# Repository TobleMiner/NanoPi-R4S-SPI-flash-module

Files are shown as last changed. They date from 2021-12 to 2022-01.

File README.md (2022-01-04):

NanoPi R4S NOR flash adapter
============================

This PCB provides the NanoPi R4S with NOR flash as a secondary or primary
boot option.  
Compared to most micro SD cards NOR flash is inherently much more reliable
due to its internal structure. While this comes with its own set of
drawbacks notably small storage size and low write speed it is very well
suited for many appliance applications.  
The dual LAN port configuration of the NanoPi R4S makes it a perfect match
for router operations. This NOR flash adapter module could for example be
paired with OpenWRT to provide a highly reliable router platform.

In addition to the SPI flash this board also features an STM32G031G6U6
microcontroller. It is connected to an I2C bus on the NanoPi R4S.  
The MCU has control over the reset and write protect lines of the SPI NOR
flash chip. Thus it can be used to disable the flash chip if booting from
alternate sources is desired. The write-protect line can be used to
implement custom tamper-proof storage designs.

To notify users of operations performed by the MCU a small dynamic
speaker is provided.

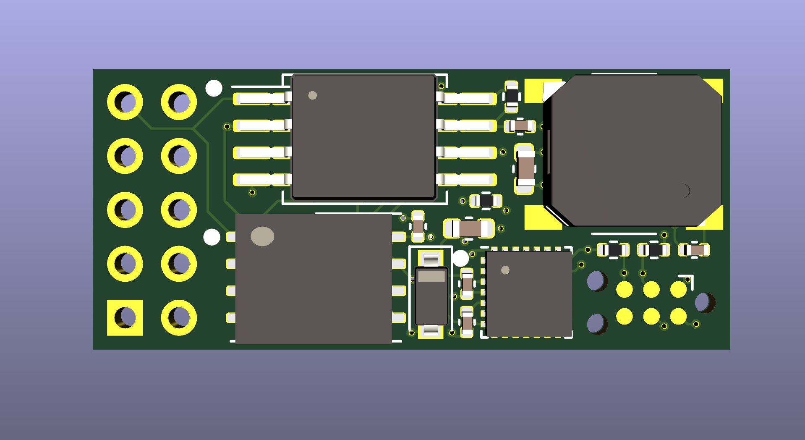
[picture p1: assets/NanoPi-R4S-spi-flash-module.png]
PCB front


# Ordering

**WARNING: Do not order rev1.0 at JLC. The partnumber for the MCU is incorrect!**

The fabrication files inside `fab` are JLCPCB-ready. I'd suggest ordering
with a 1mm board thickness. This will ensure the easiest fit in small
cases.

The board can be fully assmebled by JLC. The required fabrication files
can also be found in the `fab` directory.  
If you do not plan on using the MCU on the board you can simply unselect
the following components on JLC's website during ordering:

- U5
- D1
- LS1
- C4
- C5
- C6

This will make the boards significantly cheaper, especially when ordering
small quantities.

# Installation

Due to space constraints imposed by many cases the recommended
installation method for this board is to solder it directly to the
expansion header of the NanoPi R4S. Make sure to push the board down onto
the expansion header as far as possible before soldering it into place.

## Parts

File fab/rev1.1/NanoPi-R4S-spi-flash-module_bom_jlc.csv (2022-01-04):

Comment | Designator | Footprint | LCSC Part #
1uF | C1,C3 | C_0402_1005Metric | C52923
100nF | C2,C7 | C_0402_1005Metric | C1525
47uF | C4,C5 | C_0603_1608Metric | C140782
10uF | C6 | C_0402_1005Metric | C15525
1N4148W | D1 | D_SOD-123 | C81598
Speaker | LS1 | MLT_7525 | C95299
10k | R1,R2,R3,R4 | R_0402_1005Metric | C25744
W25Q32JVSS | U1 | SOIC-8_5.23x5.23mm_P1.27mm | C190799
STM32G031GxU | U5 | Package_QFN_ST_ST_UFQFPN-28_4x4mm_P0.5mm | C432211

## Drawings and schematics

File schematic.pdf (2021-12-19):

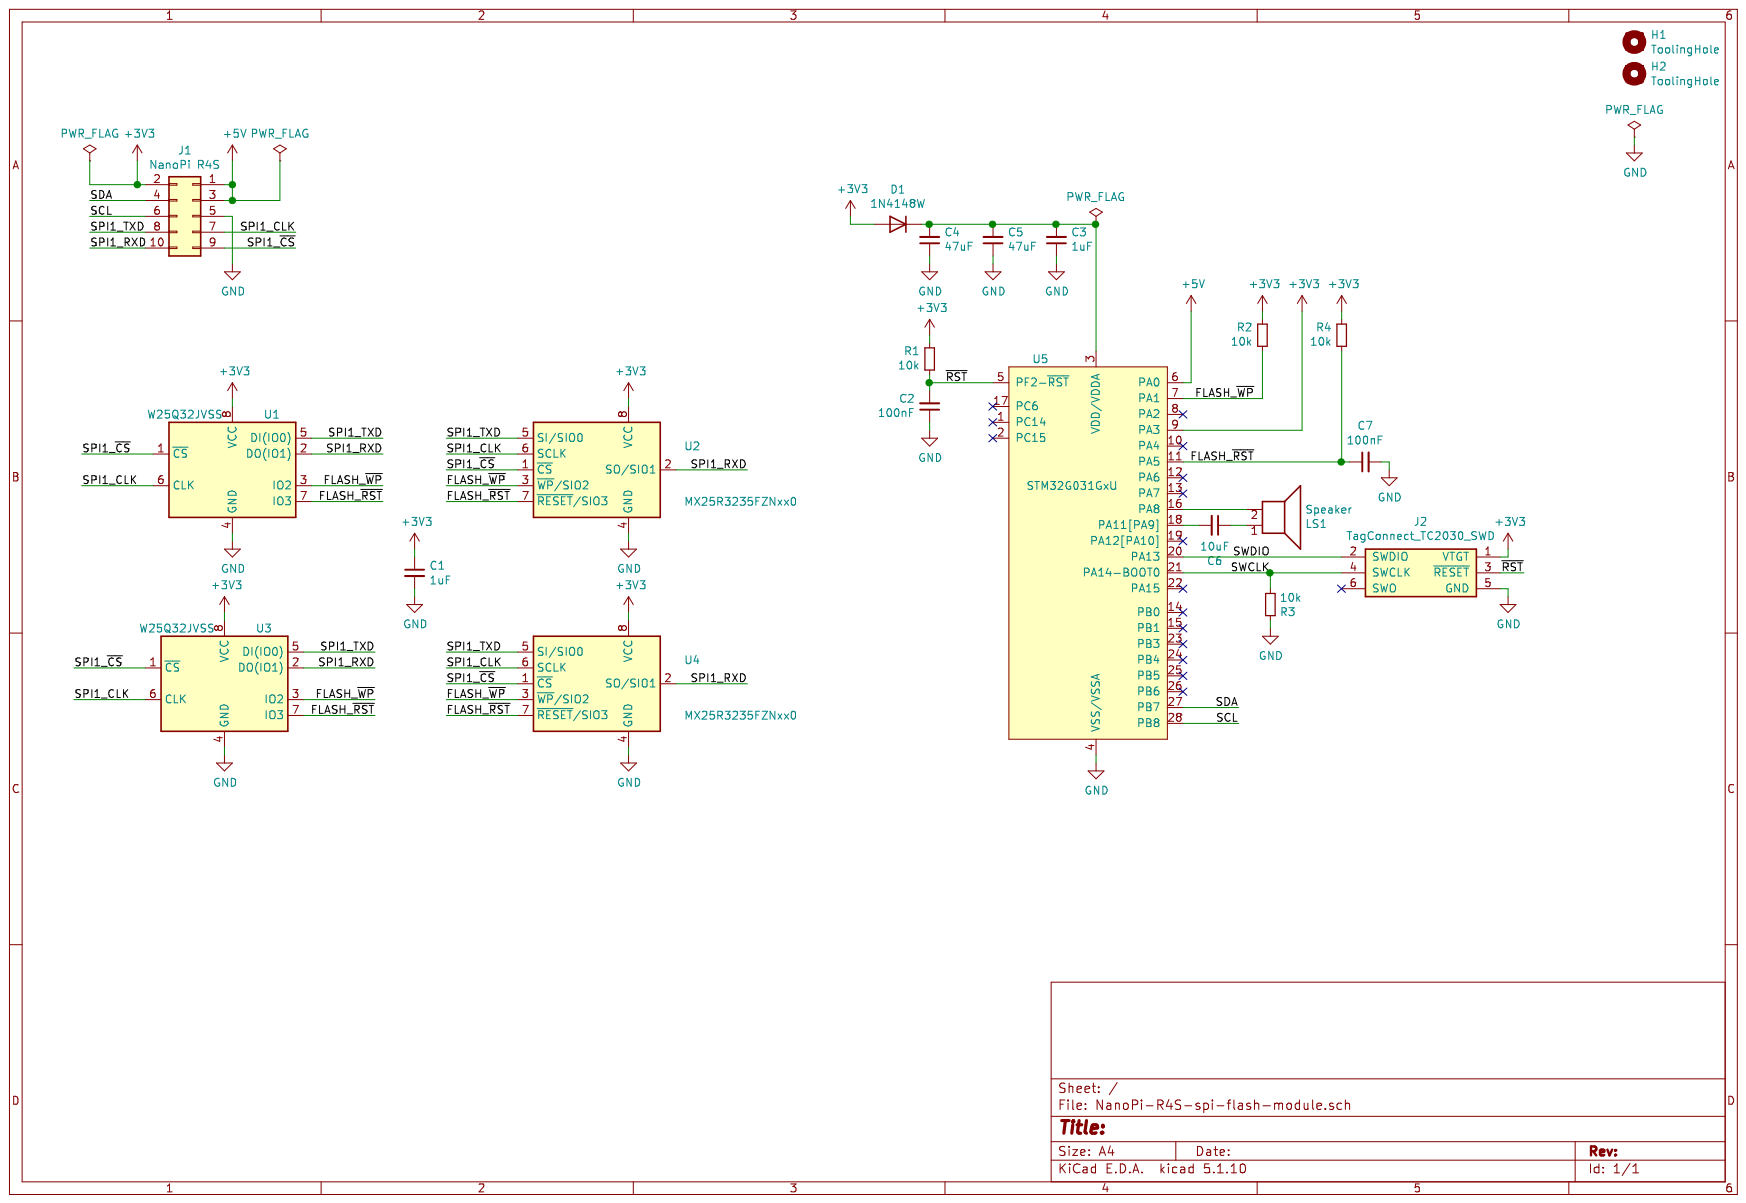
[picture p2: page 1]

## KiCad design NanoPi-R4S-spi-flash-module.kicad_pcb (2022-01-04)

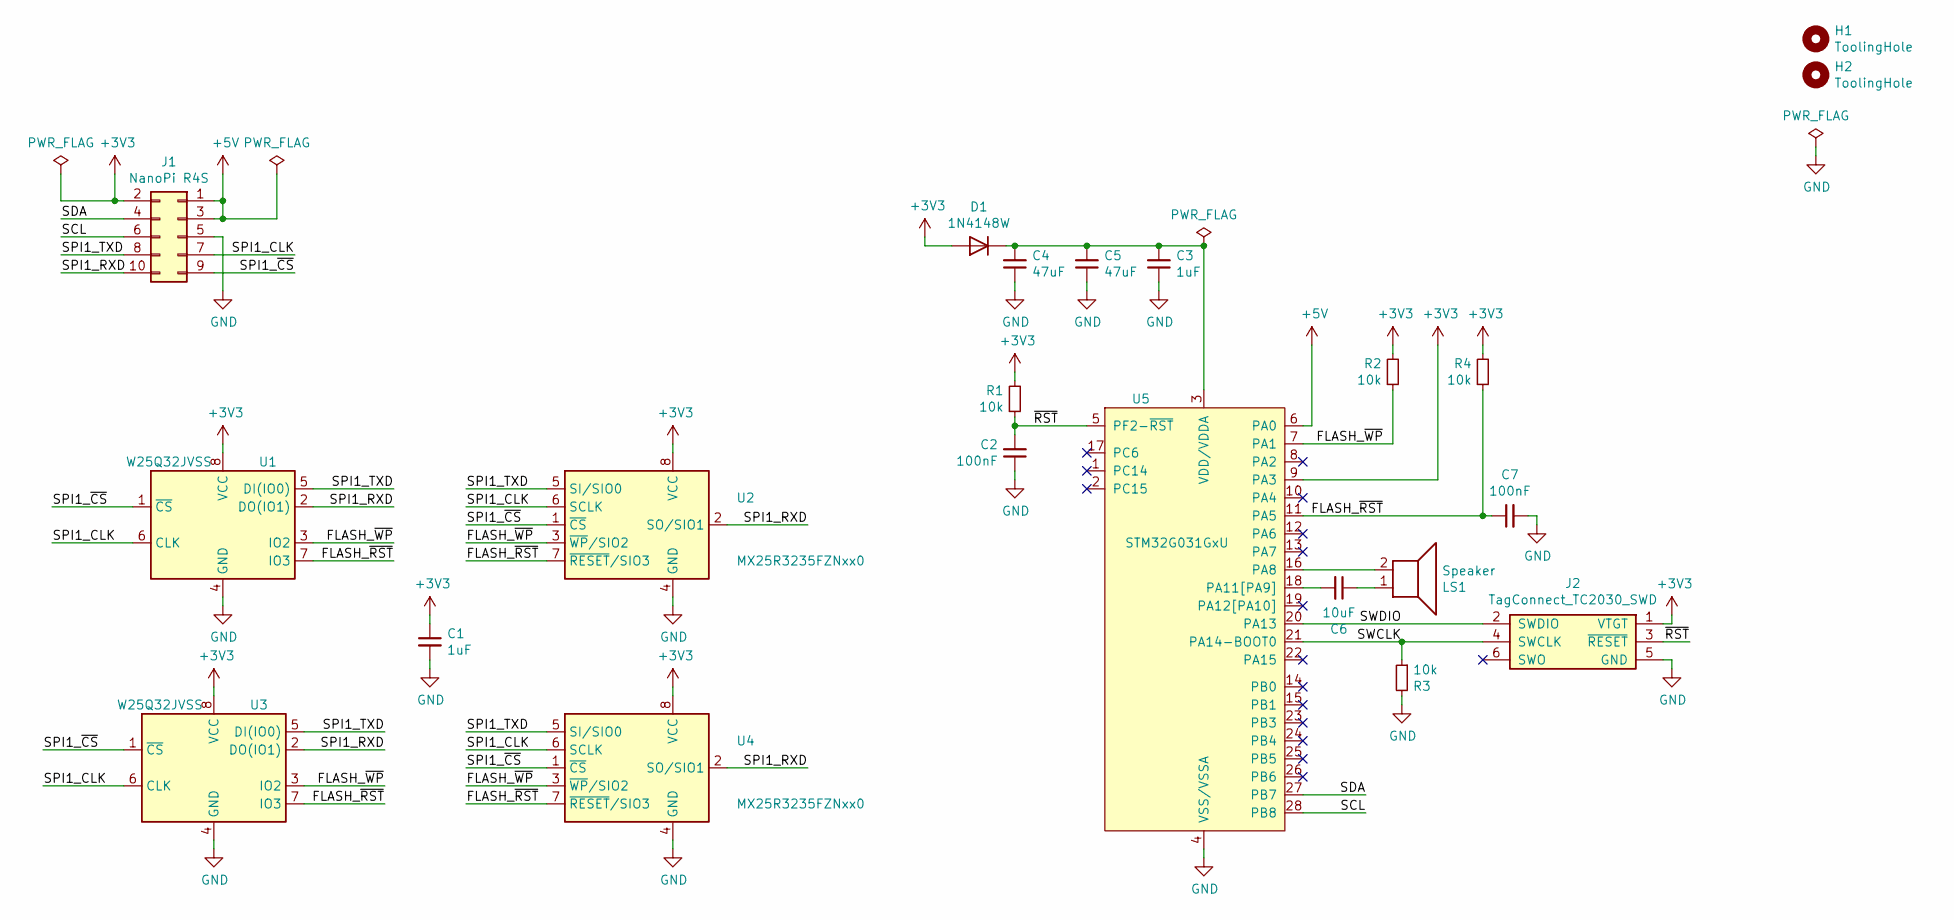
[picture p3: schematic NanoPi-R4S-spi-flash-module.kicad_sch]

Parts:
C1, C3: 1uF; C_0402_1005Metric; LCSC C52923
C2, C7: 100nF; C_0402_1005Metric; LCSC C1525
C4, C5: 47uF; C_0603_1608Metric; LCSC C140782
C6: 10uF; C_0402_1005Metric; LCSC C15525
D1: 1N4148W; D_SOD-123; LCSC C81598
H1, H2: ToolingHole; ToolingHole_JLCSMT
J1: NanoPi R4S; PinHeader_2x05_P2.54mm_Vertical
J2: TagConnect_TC2030_SWD; Tag-Connect_TC2030-IDC-NL_2x03_P1.27mm_Vertical
LS1: Speaker; MLT_7525; LCSC C95299
R1, R2, R3, R4: 10k; R_0402_1005Metric; LCSC C25744
U1: W25Q32JVSS; SOIC-8_5.23x5.23mm_P1.27mm; LCSC C190799
U2: MX25R3235FZNxx0; WSON-8-1EP_6x5mm_P1.27mm_EP3.4x4mm
U3: W25Q32JVSS; SOIC-8_7.5x5.85mm_P1.27mm
U4: MX25R3235FZNxx0; WSON-8-1EP_8x6mm_P1.27mm_EP3.4x4.3mm
U5: STM32G031GxU; Package_QFN_ST_ST_UFQFPN-28_4x4mm_P0.5mm; LCSC C432211

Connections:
+3V3: C1.1, D1.2 (A), J1.2, J2.1 (VTGT), R1.2, R2.2, R4.2, U1.8 (VCC), U2.8 (VCC), U3.8 (VCC), U4.8 (VCC), U5.9 (PA3)
+5V: J1.1, J1.3, U5.6 (PA0)
/FLASH_~RST: C7.1, R4.1, U1.7 (IO3), U2.7 (~RESET/SIO3), U3.7 (IO3), U4.7 (~RESET/SIO3), U5.11 (PA5)
/FLASH_~WP: R2.1, U1.3 (IO2), U2.3 (~WP/SIO2), U3.3 (IO2), U4.3 (~WP/SIO2), U5.7 (PA1)
/SCL: J1.6, U5.28 (PB8)
/SDA: J1.4, U5.27 (PB7)
/SPI1_CLK: J1.7, U1.6 (CLK), U2.6 (SCLK), U3.6 (CLK), U4.6 (SCLK)
/SPI1_RXD: J1.10, U1.2 (DO(IO1)), U2.2 (SO/SIO1), U3.2 (DO(IO1)), U4.2 (SO/SIO1)
/SPI1_TXD: J1.8, U1.5 (DI(IO0)), U2.5 (SI/SIO0), U3.5 (DI(IO0)), U4.5 (SI/SIO0)
/SPI1_~CS: J1.9, U1.1 (~CS), U2.1 (~CS), U3.1 (~CS), U4.1 (~CS)
/SWCLK: J2.4 (SWCLK), R3.1, U5.21 (PA14-BOOT0)
/SWDIO: J2.2 (SWDIO), U5.20 (PA13)
/~RST: C2.2, J2.3 (~RESET), R1.1, U5.5 (PF2-~RST)
GND: C1.2, C2.1, C3.1, C4.1, C5.1, C7.2, J1.5, J2.5 (GND), R3.2, U1.4 (GND), U2.4 (GND), U2.9 (GND), U3.4 (GND), U4.4 (GND), U4.9 (GND), U5.4 (VSS/VSSA)
unnamed: C3.2, C4.2, C5.2, D1.1 (K), U5.3 (VDD/VDDA)
unnamed: C6.1, LS1.1
unnamed: C6.2, U5.18 (PA11[PA9])
unnamed: LS1.2, U5.16 (PA8)

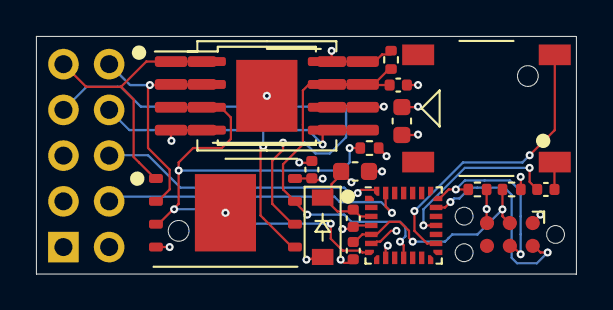
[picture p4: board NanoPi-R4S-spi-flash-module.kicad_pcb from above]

Board: 4 copper layers, 30.0 x 13.2 mm, 22 parts (1 on the bottom side), 18 nets.

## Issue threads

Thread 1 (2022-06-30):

JLCPCB order options

pogduhog, 2022-06-30:
Thank you very much for providing this. Could you provide some guidance on how to structure the order through JLCPCB? I can get as far as uploading the Gerber files and changing the thickness to 1mm as mentioned, however my complete ignorance in this field prevents me from understanding any of the other options. From what I understand the defaults look alright, do I need to specify the layer order, or anything else specific?

Thanks again,

Pog

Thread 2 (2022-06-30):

JLCPCB

pogduhog, 2022-06-30:
Thank you very much for providing this. Could you provide some guidance on how to structure the order through JLCPCB? I can get as far as uploading the Gerber files and changing the thickness to 1mm as mentioned, however my complete ignorance in this field prevents me from understanding any of the other options. From what I understand the defaults look alright, do I need to specify the layer order, or anything else specific?

Thanks again,

Pog

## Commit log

2021-12-19 Replace D1 by regular silicon diode
    Schottky diodes tend to have high leakage current. Considering the MCU is
    supposed to be kept running on C4 and C5 as long as possible after power
    has been removed reducing leakage current back into the 3.3V supply rail
    is key.
    Replace D1 by an ordinary 1N4148 to minimize leakage current back into the
    3.3V supply rail.
    [NanoPi-R4S-spi-flash-module.kicad_pcb, NanoPi-R4S-spi-flash-module.sch, NanoPi-R4S-spi-flash-module_bom_jlc.csv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]
2021-12-19 Hide D1 designator
    [NanoPi-R4S-spi-flash-module.kicad_pcb]
2022-01-04 Fix incorrect MCU partnumber
    [NanoPi-R4S-spi-flash-module.kicad_pcb, NanoPi-R4S-spi-flash-module.kicad_sch]
2022-01-04 Rev 1.1
    Changelog:
    - fix incorrect MCU JLC partnumber
    [NanoPi-R4S-spi-flash-module_bom_jlc.csv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]
